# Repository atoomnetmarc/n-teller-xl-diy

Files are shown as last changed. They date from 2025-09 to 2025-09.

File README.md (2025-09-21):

**Status**: finished and working.

**Soldering and assembly time**: about 4 hours (if you can solder well).

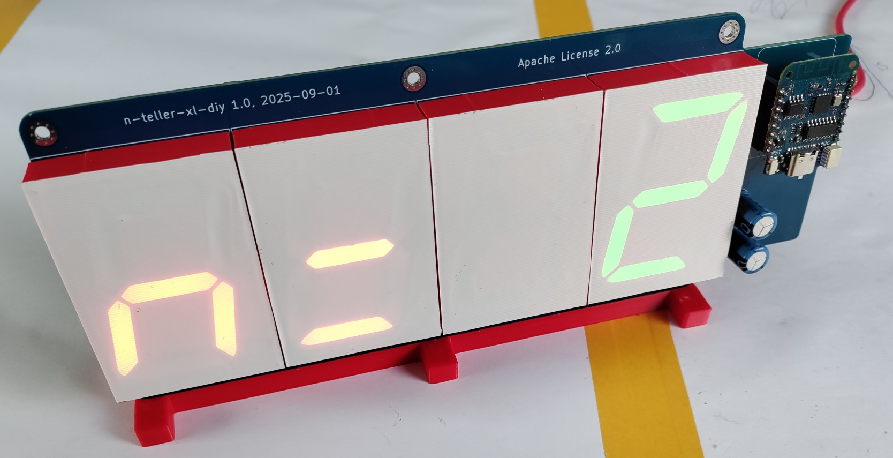
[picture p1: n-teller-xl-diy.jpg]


# n-teller-xl-diy

n-teller-xl-diy is an IoT device that displays the number of [checked in participants and visitors](https://revspace.nl/N) at the hackerspace called [Revelation Space (or RevSpace)](https://revspace.nl).

It connects to the [RevSpace MQTT server](https://revspace.nl/MQTT) via WiFi using an ESP8266.

The MQTT server publishes to [a few topics of interest](https://revspace.nl/MQTT#Topics) that are subscribed:

- revspace/[doorduino](https://revspace.nl/Doorduino3)/checked-in: this is the current total of checked-in people.
- revspace/[state](https://revspace.nl/Spacestatus): the current state (open or closed) of the hackerspace.

# Schematic

[hardware/n-teller-xl-diy-schematic.pdf](hardware/n-teller-xl-diy-schematic.pdf)

# BOM

See interactive BOM: [hardware/bom/](https://html-preview.github.io/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)

You will also need:

- The pcb. See [hardware/gerber/](hardware/gerber/) for gerber files. Order it at some PCB fabricator. You can also ask me for a bare PCB when I am at [RevSpace](https://revspace.nl/) hackerspace. I may have some left. I sell them for €5 a piece.
- 4x 3D prints of `7-segment 2.3 inch.stl` in opaque colored plastic. Use Gyroid infill for strong screw holes.
- 1x 3D print of `n-teller-xl-diy-stand.stl` in the color of your choice.
- 16x M2x10 self-tapping hex screws to mount the 4 7-segment 3D prints to the PCB.
- 3x M3x12 BHCS screws to mount the PCB to the 3D printed stand.
- About 28cm of 5cm wide vinyl white tape to stick onto the face of the 3D printed 7-segment digits. Or some other kind of 20x8cm thin white sticky plastic.

# Render

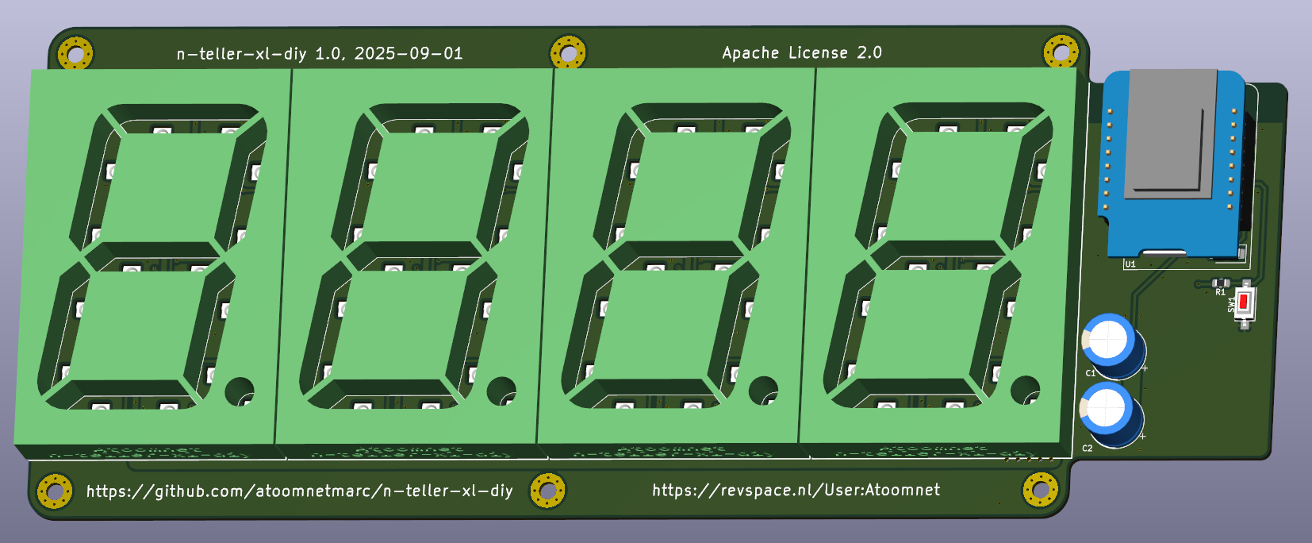
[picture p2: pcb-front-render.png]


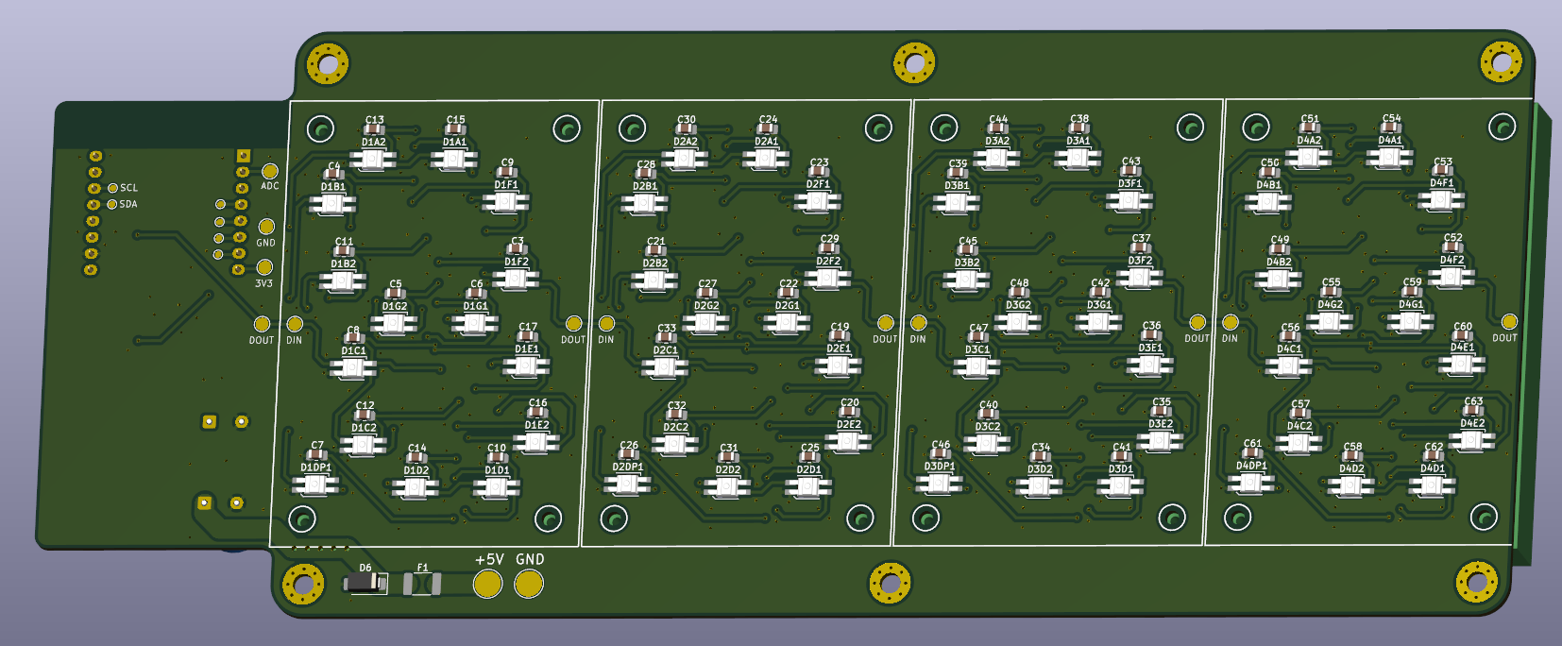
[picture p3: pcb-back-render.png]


# Assembly

Last time I made assembly instructions for the [n-teller](https://github.com/atoomnetmarc/n-teller) at https://revspace.nl/N-teller, but that was not used, everybody just asked what to do, even after telling there are assembly instructions.

So for this one I won't make instructions. Just follow the BOM and look at the pictures on this page, and figure things out yourself.

Use a 5V power supply that can provide at least 1A.

# Firmware

Compile and flash the firmware located in the [firmware directory](firmware/). You will need [PlatformIO](https://platformio.org/) for this. I recommend installing the [PlatformIO extension for VSCode](https://platformio.org/install/ide?install=vscode).

# Configure WiFi

Double press the reset button (somewhat slowly). The letters `AP` will appear on the display. Now connect to a WiFi network with a name like `nteller-bcddc2895fd2`. Then goto: http://192.168.4.1/ and configure your WiFi.

# (Frequently) Asked Questions

> Do I really need the level shifter?
>
> -- <cite>User that does not know that the high signal level of 3.3V is lower than the VIH (3.5V) of the SK6812</cite>

Oh, sure, because nothing says "reliable electronics" like ignoring basic signal integrity! No, you don't *really* need the level shifter. Just blob some solder on `JP1` and cross your fingers that your 3.3V signals magically play nice with those finicky SK6812s. But when your display starts glitching like it's possessed by a deranged hacker, don't you dare come whining to me – after all, you're the self-proclaimed expert who thought this was a brilliant idea. Good luck with that masterpiece!

On serious note. It depends. I had 2 batches of SK6812 LEDS's. One batch worked on 3.3V DIN, but VCC must be below 5.1V, any higher and it did not work. The other batch did not work, even after lowering VCC to below 4.5V. So, yes, you need a level shifter.



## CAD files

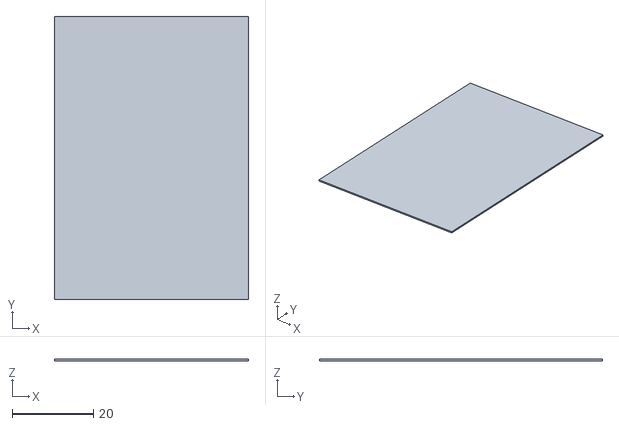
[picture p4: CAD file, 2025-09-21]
3d/7-segment 2.3 inch optional diffuser.stl
47.8 x 69.7 x 0.4

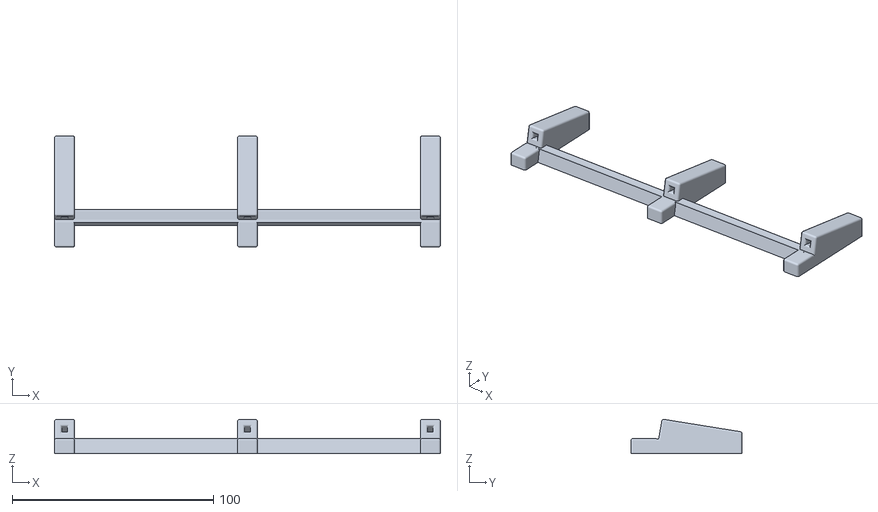
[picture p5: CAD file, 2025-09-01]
3d/n-teller-xl-diy-stand.stl
191.6 x 55.2 x 17.0

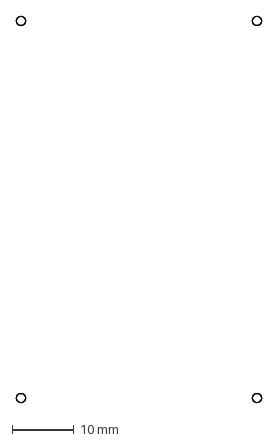
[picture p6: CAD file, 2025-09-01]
3d/7-segment 2.3 inch holes.dxf
39.6 x 62.5 mm

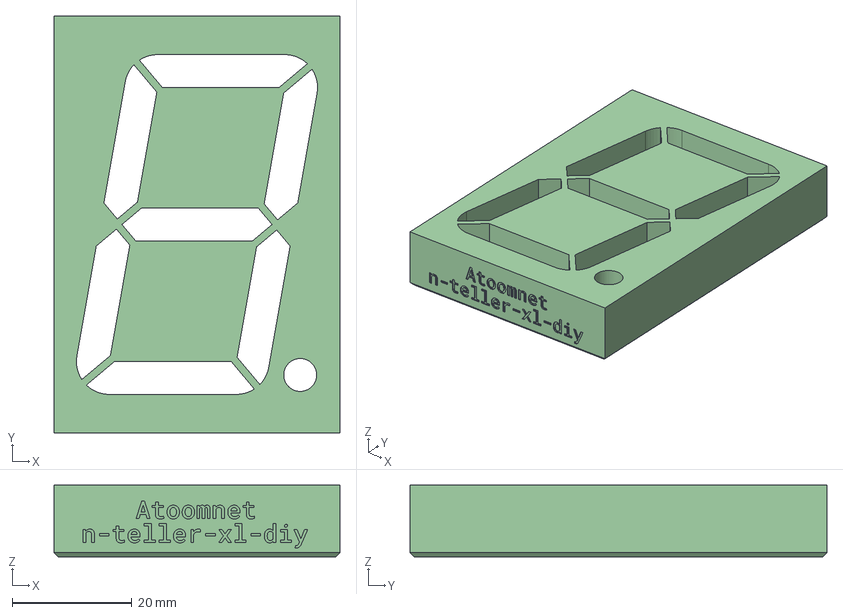
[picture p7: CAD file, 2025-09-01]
3d/7-segment 2.3 inch.step
47.8 x 69.7 x 12.0 mm

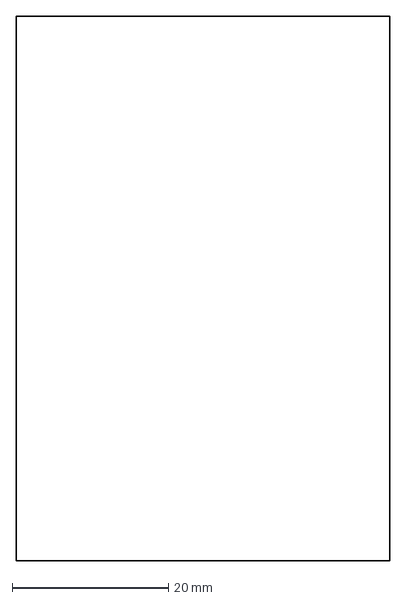
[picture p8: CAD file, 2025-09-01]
3d/7-segment 2.3 inch outline.dxf
47.8 x 69.7 mm

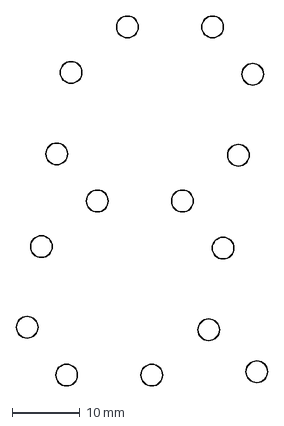
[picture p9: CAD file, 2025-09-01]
3d/7-segment 2.3 inch led position.dxf
37.1 x 54.5 mm

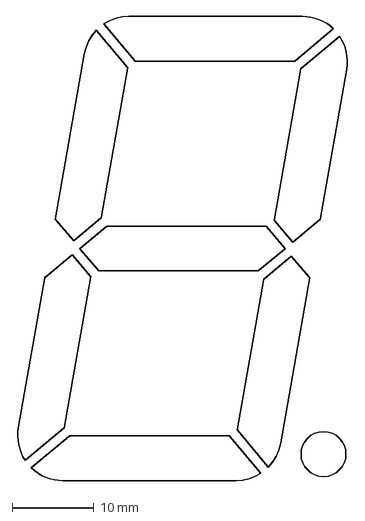
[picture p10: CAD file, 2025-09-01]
3d/7-segment 2.3 inch segments.dxf
40.6 x 56.8 mm

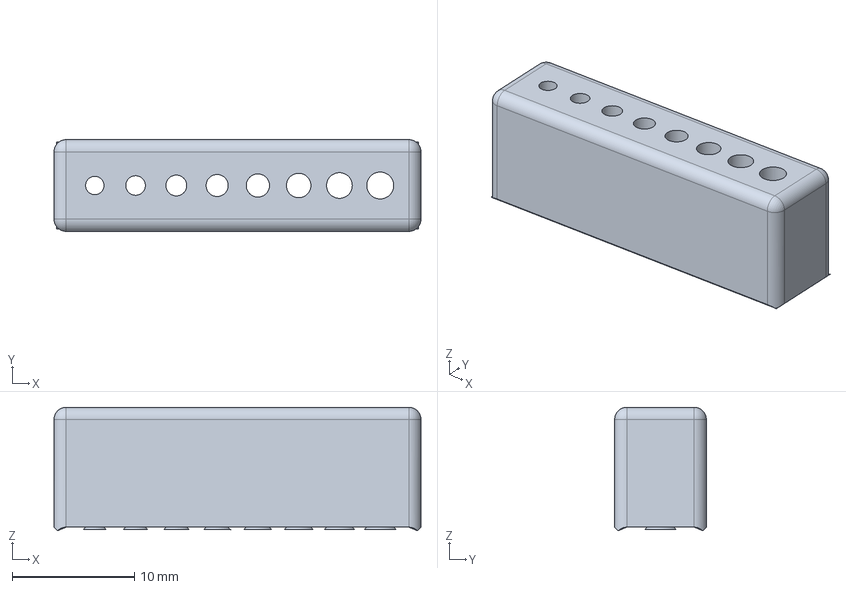
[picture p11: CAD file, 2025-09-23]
3d/m2x10 hole tester.FCStd
30.0 x 7.50 x 10.1 mm

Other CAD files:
3d/7-segment 2.3 inch.FCStd
3d/7-segment 2.3 inch.stl
3d/m2x10 hole tester.stl

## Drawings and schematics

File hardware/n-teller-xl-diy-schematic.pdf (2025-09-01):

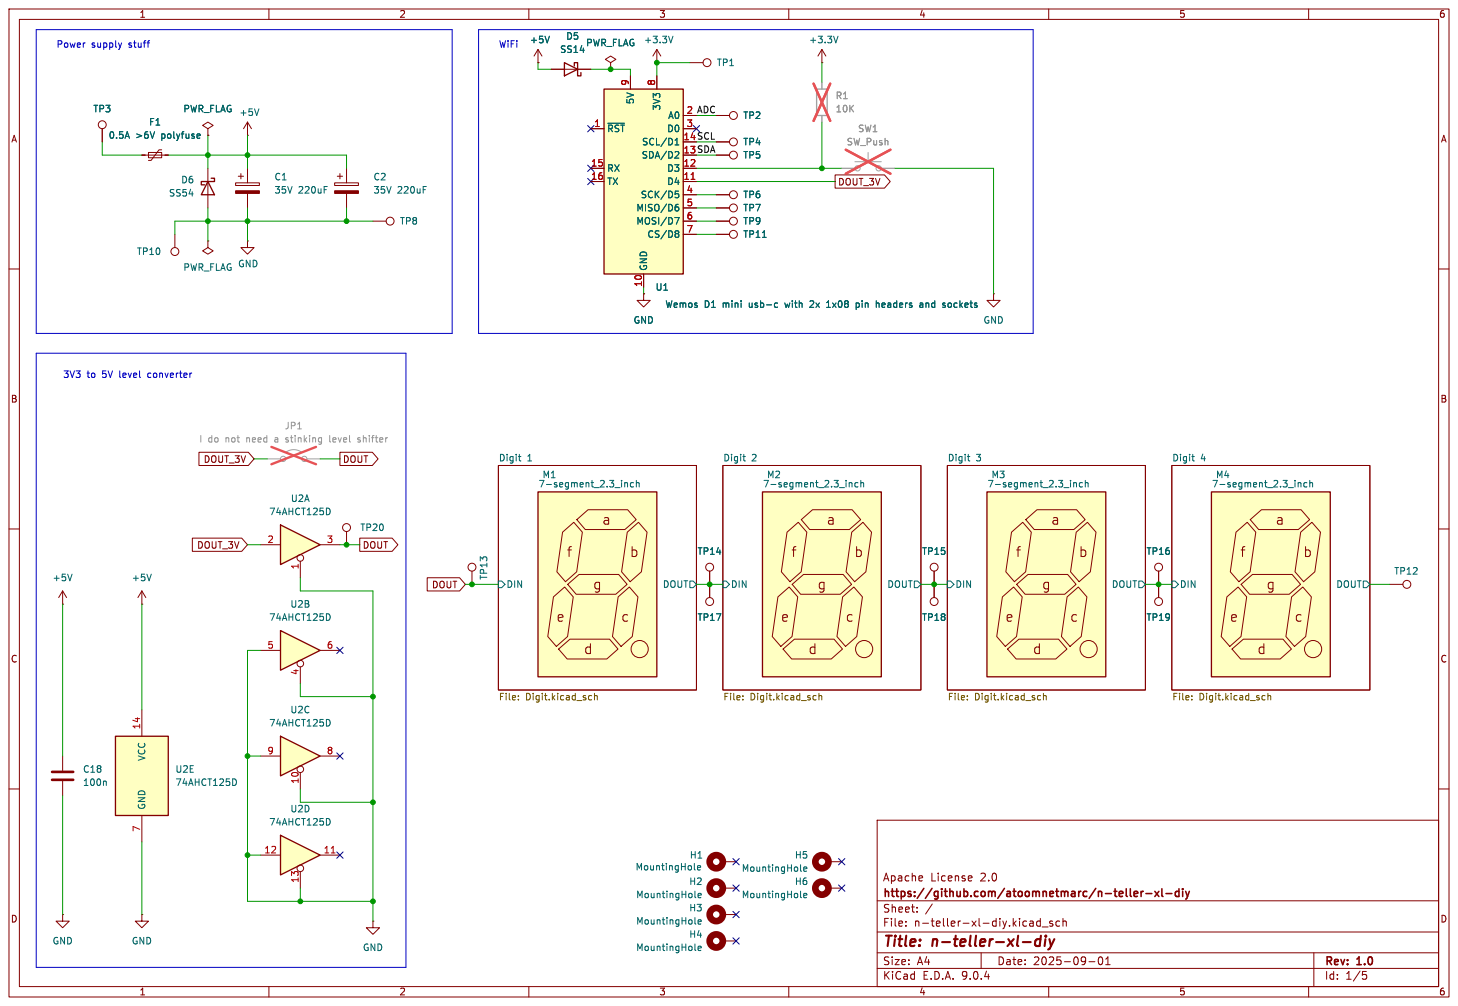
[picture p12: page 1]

8 A0 2 D0 3 SCL/D1 14 SDA/D2 13 D3 12 D4 11 SCK/D5 4 MISO/D6 5 MOSI/D7 6 CS/D8 7 SW1 SW_Push GND

8 A0 2 D0 3 SCL/D1 14 SDA/D2 13 D3 12 D4 11 SCK/D5 4 MISO/D6 5 MOSI/D7 6 CS/D8 7 U1Wemos D1 mini usb-c with 2x 1x08 pin headers and sockets TP5 TP6 TP7 H5 MountingHoleH6 MountingHole

File: n-teller-xl-diy.kicad_sch Sheet: / https://github.com/atoomnetmarc/n-teller-xl-diy

Id: 1/5 Title: n-teller-xl-diy

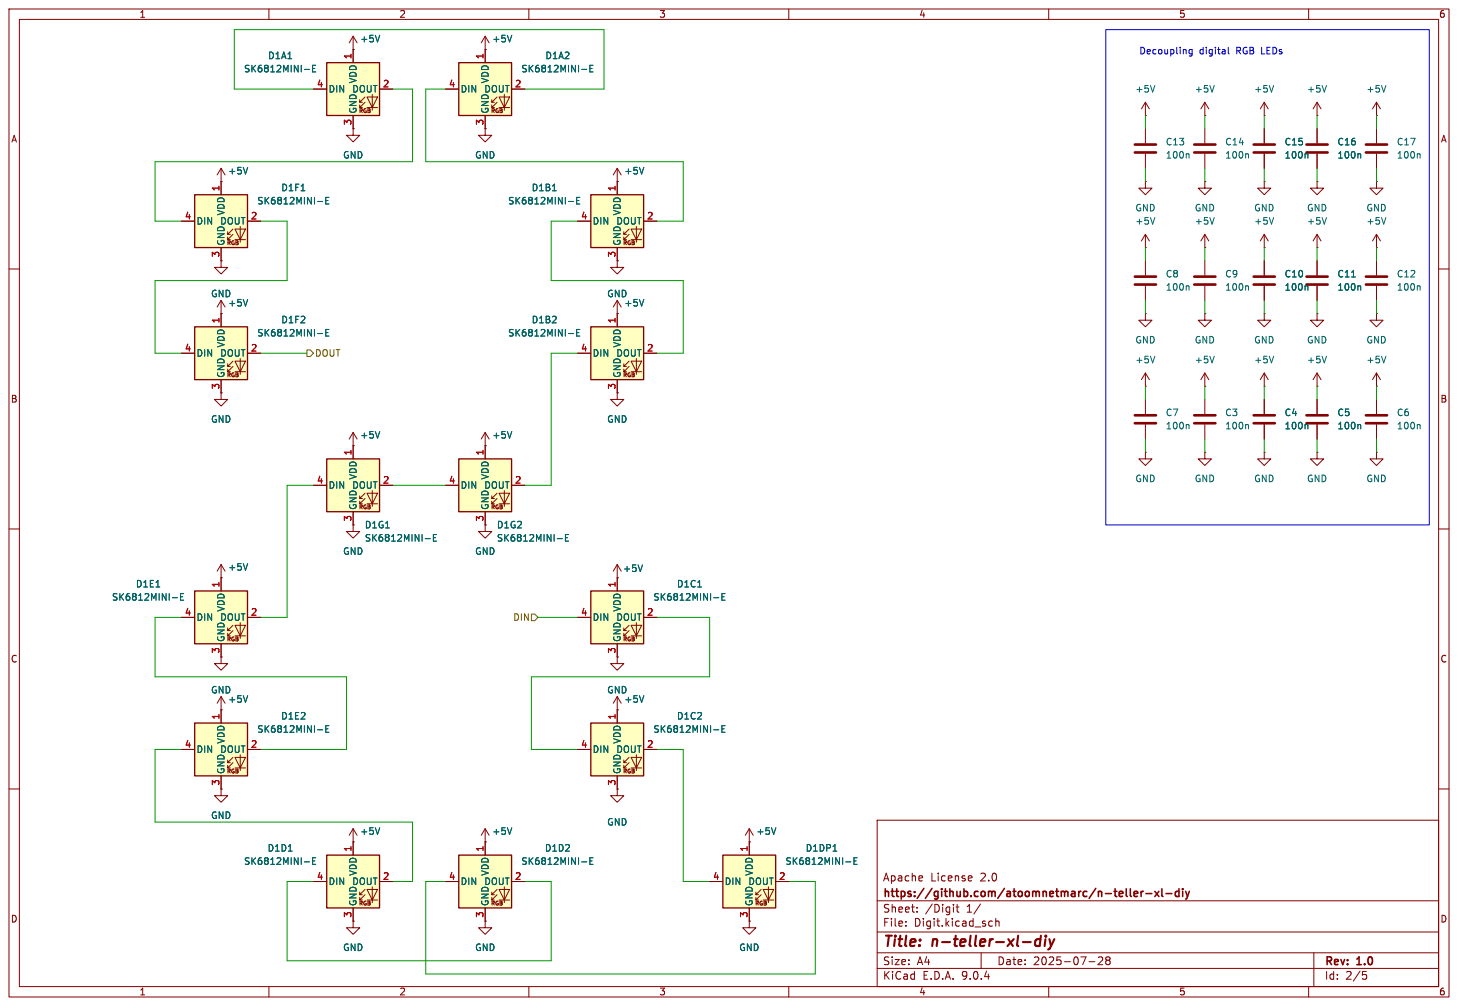
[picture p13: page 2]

Id: 2/5 Title: n-teller-xl-diy

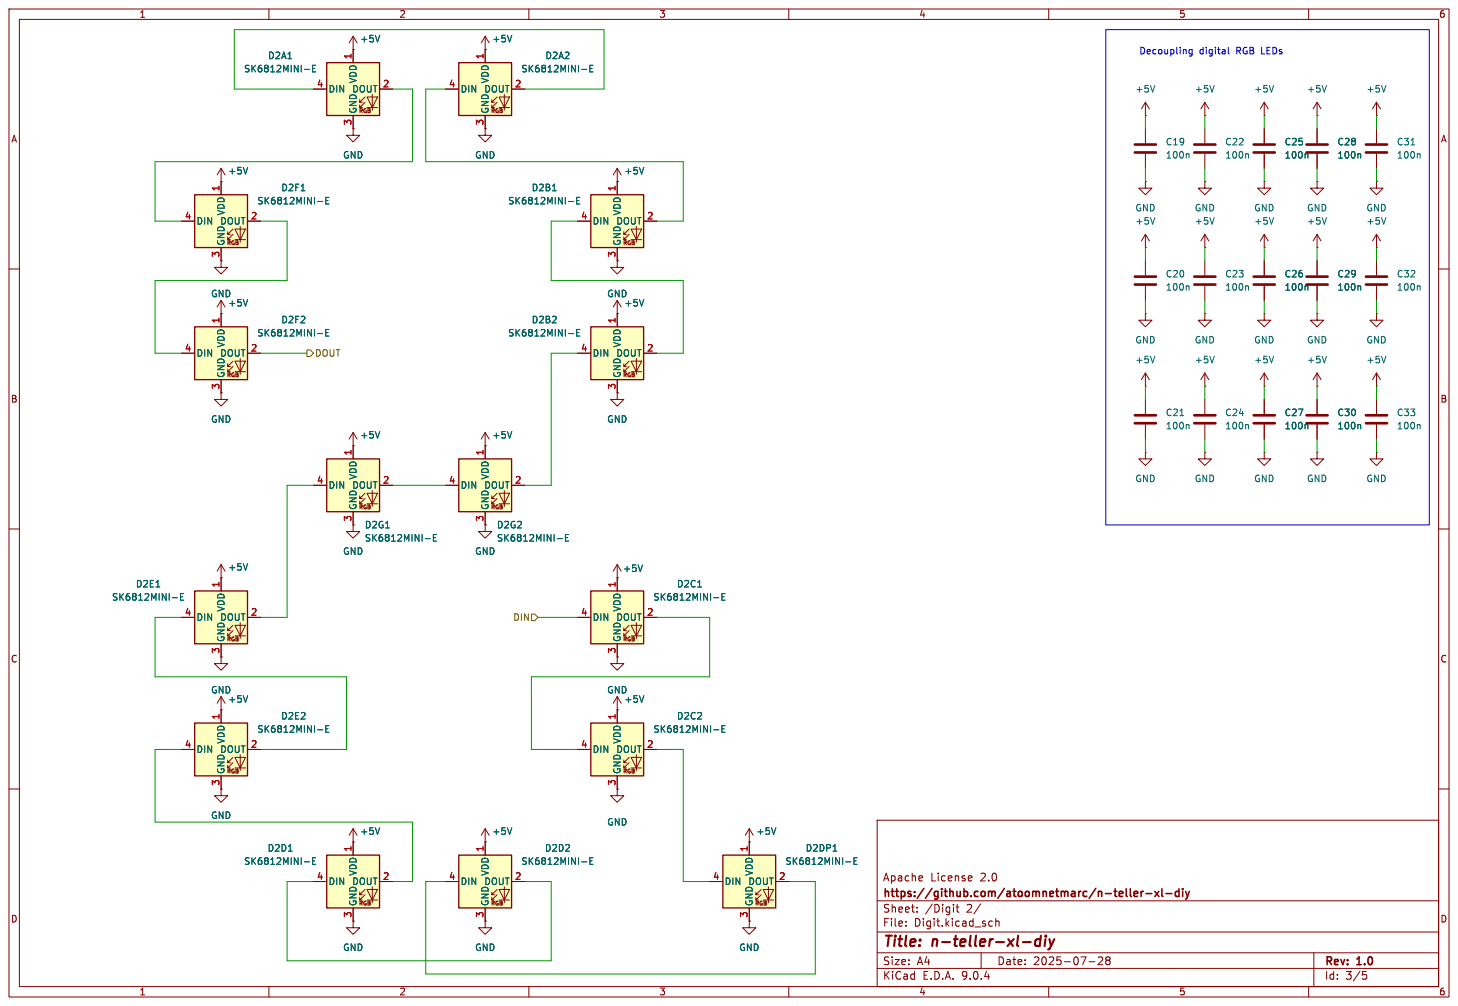
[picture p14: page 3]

Id: 3/5 Title: n-teller-xl-diy

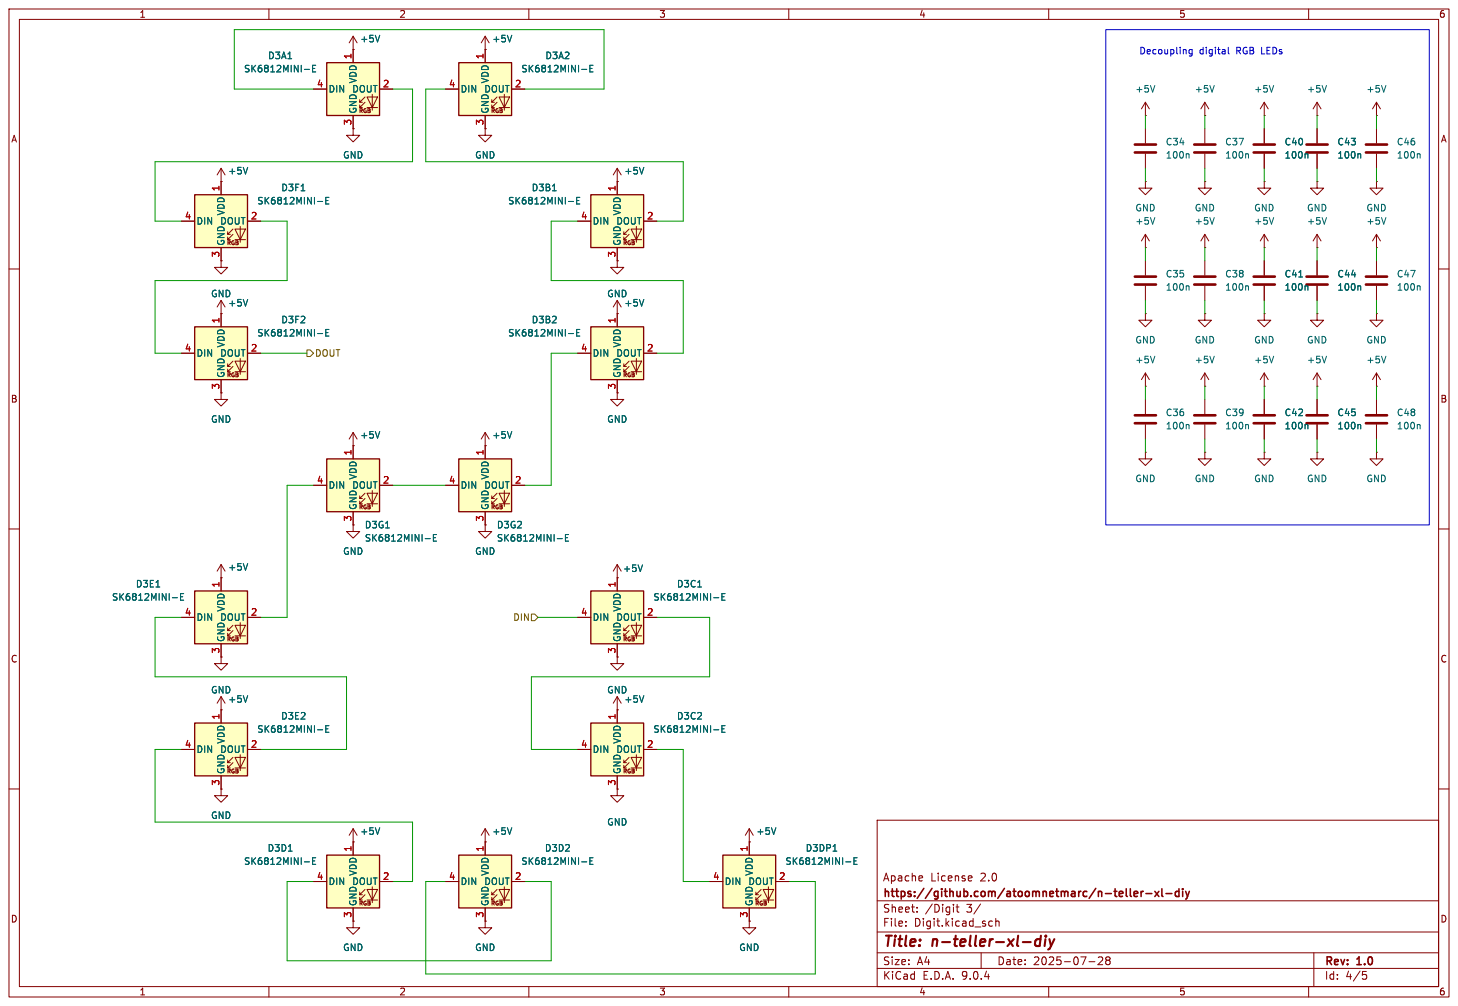
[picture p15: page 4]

Id: 4/5 Title: n-teller-xl-diy

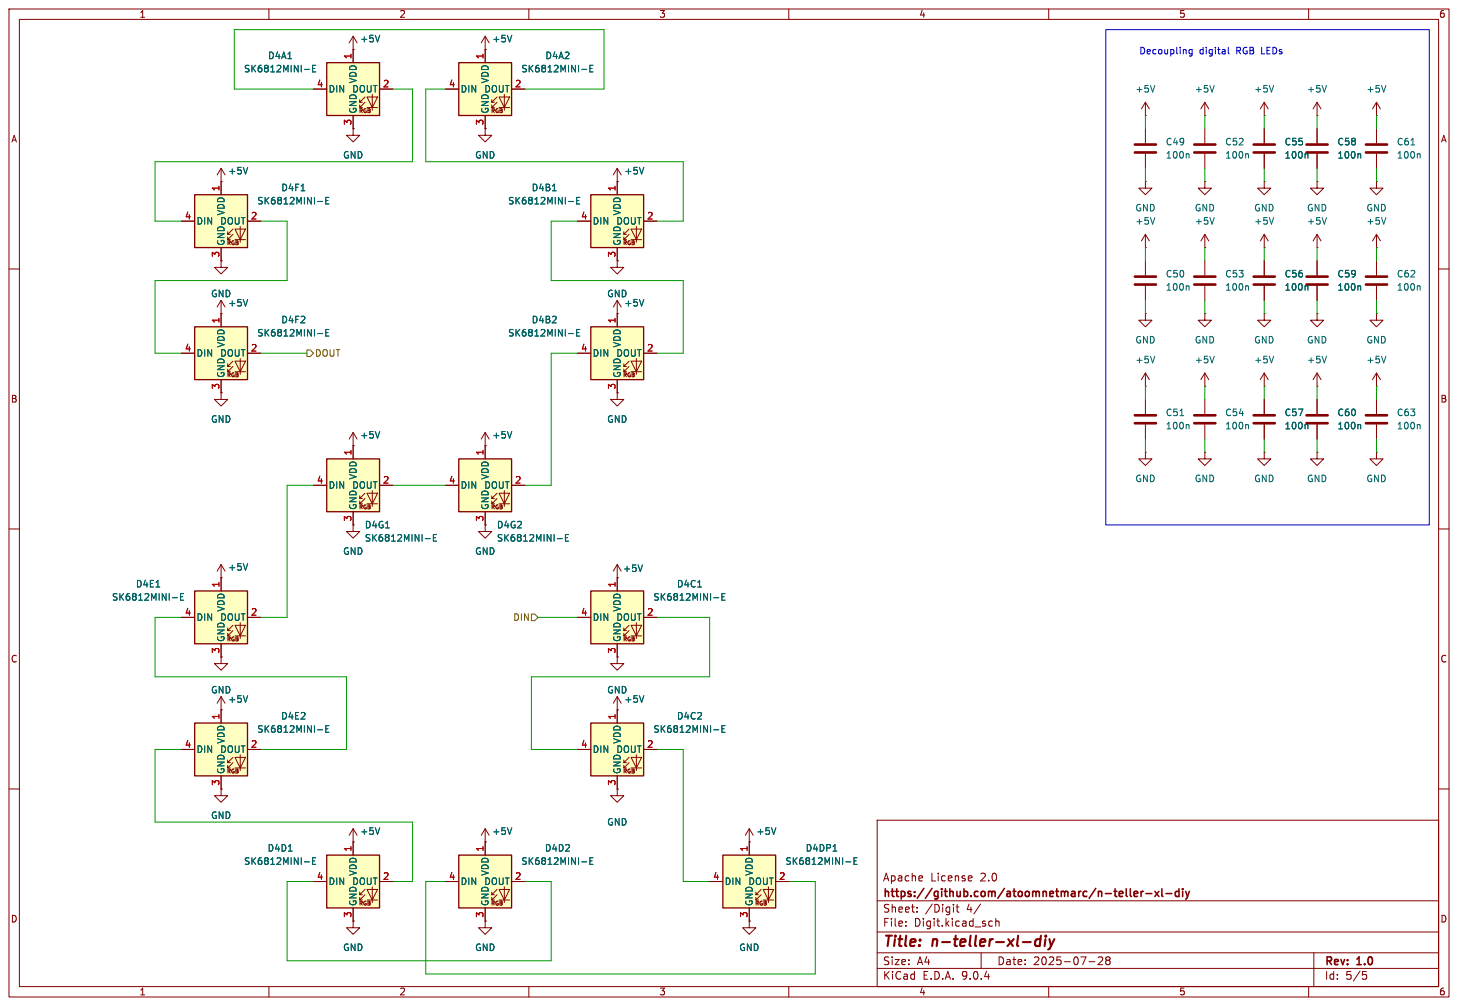
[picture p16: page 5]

Id: 5/5 Title: n-teller-xl-diy

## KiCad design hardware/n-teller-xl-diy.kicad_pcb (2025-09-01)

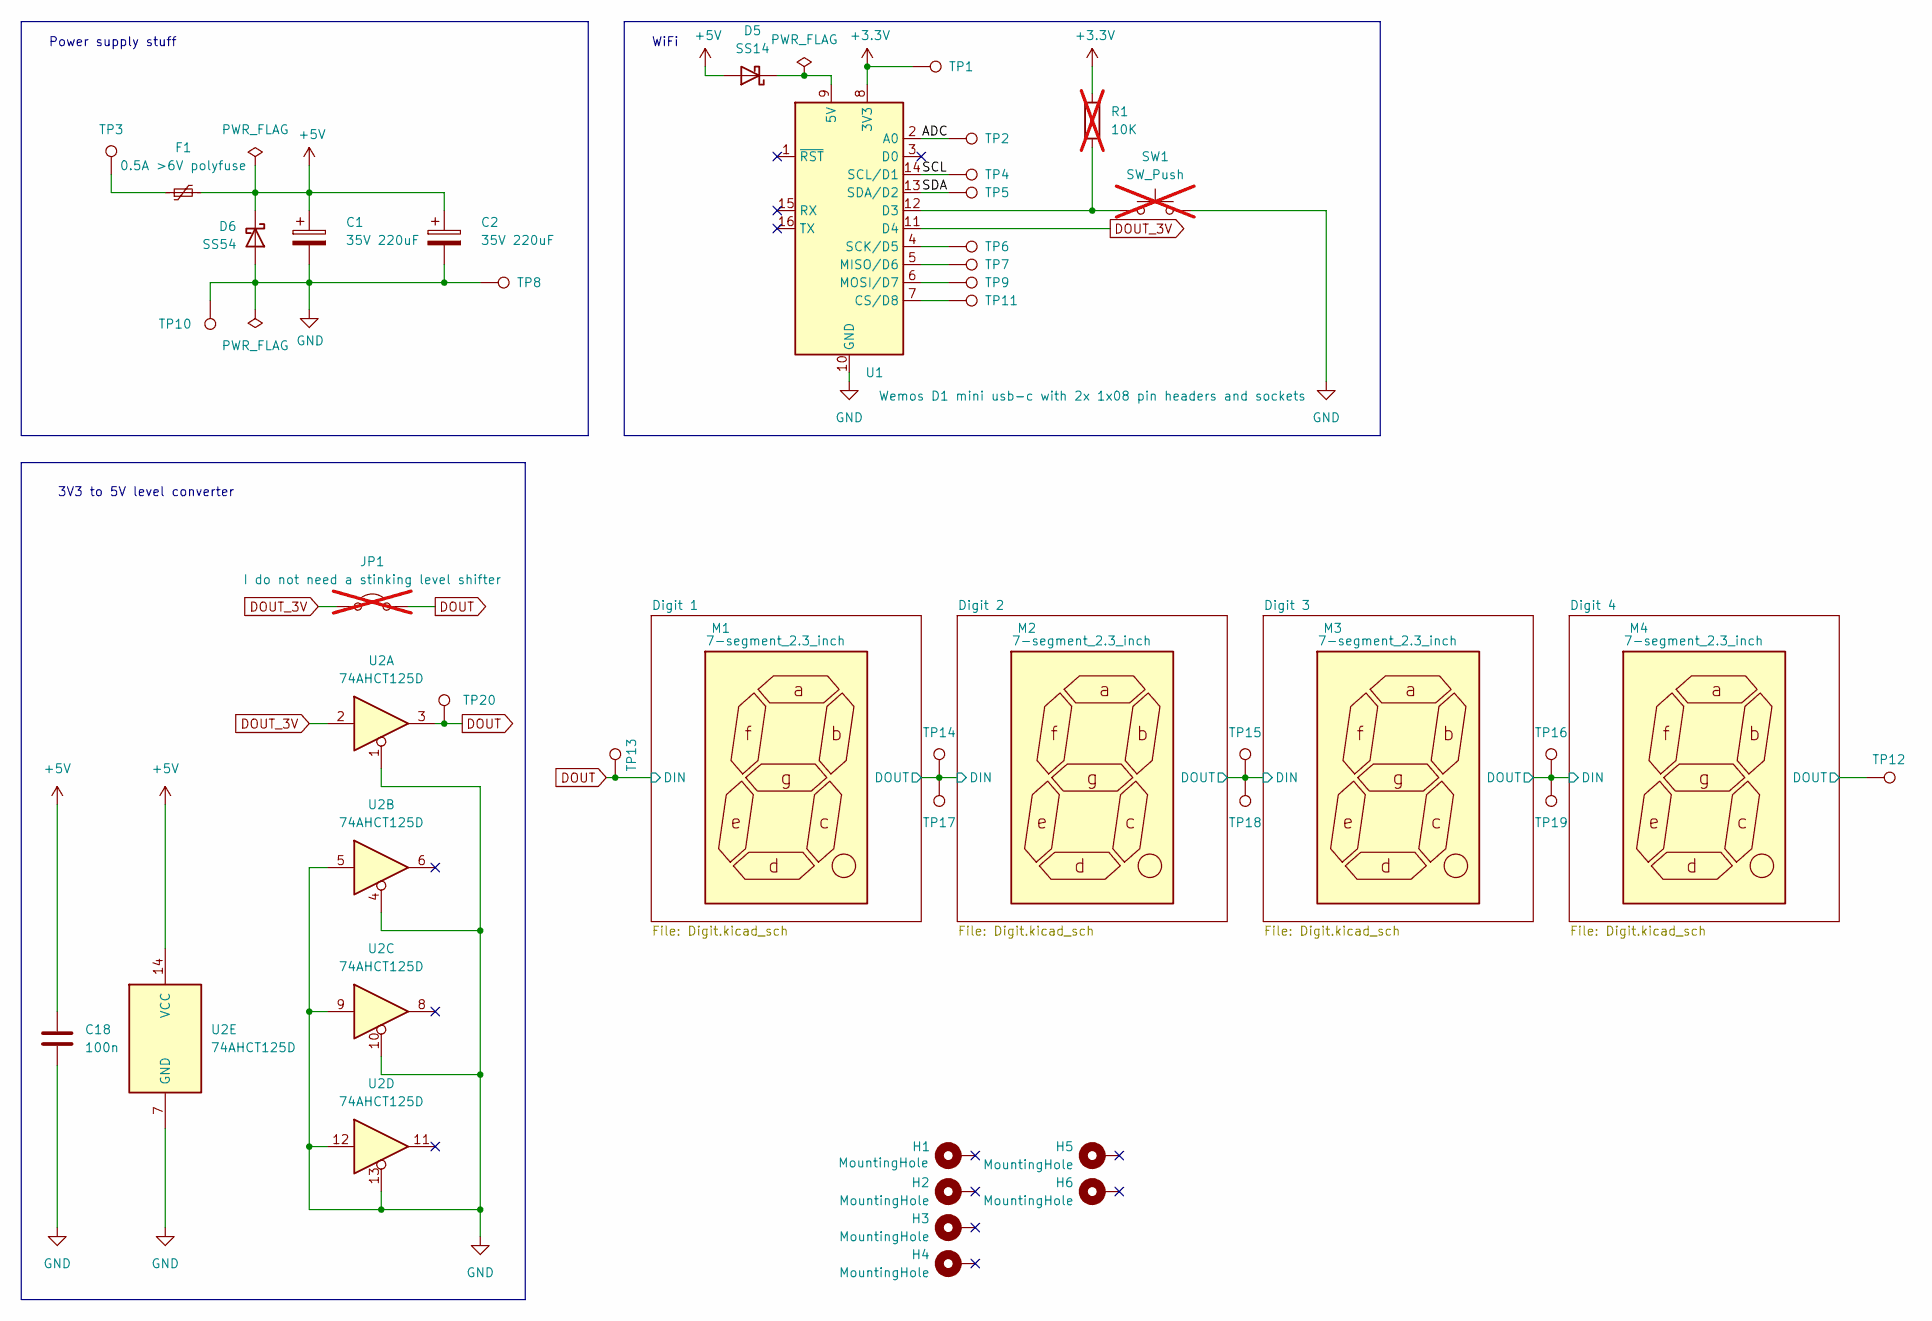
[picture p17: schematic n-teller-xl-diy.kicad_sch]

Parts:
C1, C2: 35V 220uF; CP_Radial_D10.0mm_P5.00mm
C18: 100n; C_0805_2012Metric_Pad1.18x1.45mm_HandSolder
D5: SS14; D_SMA
D6: SS54; D_SMA
F1: 0.5A >6V polyfuse; Fuse_1812_4532Metric_Pad1.30x3.40mm_HandSolder
H1, H2, H3, H4, H5, H6: MountingHole; MountingHole_3.2mm_M3_Pad_Via
JP1: I do not need a stinking level shifter; SolderJumper-2_P1.3mm_Open_TrianglePad1.0x1.5mm; not fitted
M1, M2, M3, M4: 7-segment_2.3_inch; 3d-printed 7-segment 2.3 inch
R1: 10K; R_0805_2012Metric_Pad1.20x1.40mm_HandSolder; not fitted
SW1: SW_Push; SW_SPST_CK_RS282G05A3; not fitted
TP1, TP2, TP8, TP12, TP13, TP14, TP15, TP16, TP17, TP18, TP19, TP20: TestPoint; TestPoint_Pad_D2.0mm
TP3, TP10: TestPoint; TestPoint_Pad_D4.0mm
TP4, TP5, TP6, TP7, TP9, TP11: TestPoint; TestPoint_Pad_D1.0mm
U1: Wemos D1 mini usb-c with 2x 1x08 pin headers and 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; WEMOS_D1_mini
U2: 74AHCT125D; SOIC-14_3.9x8.7mm_P1.27mm

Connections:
+3.3V: R1.2, TP1.1, U1.8 (3V3)
+5V: C1.1, C2.1, C18.1, D5.2 (A), D6.1 (K), F1.2, U2.14 (VCC); also elsewhere on the board
/ADC: TP2.1, U1.2 (A0)
/Digit 1/DOUT: TP14.1, TP17.1; also elsewhere on the board
/Digit 2/DOUT: TP15.1, TP18.1; also elsewhere on the board
/Digit 3/DOUT: TP16.1, TP19.1; also elsewhere on the board
/Digit 4/DOUT: TP12.1; also elsewhere on the board
/SCL: TP4.1, U1.14 (SCL/D1)
/SDA: TP5.1, U1.13 (SDA/D2)
DOUT: JP1.2 (B), TP13.1, TP20.1, U2.3; also elsewhere on the board
DOUT_3V: JP1.1 (A), U1.11 (D4), U2.2
GND: C1.2, C2.2, C18.2, D6.2 (A), SW1.1, TP8.1, TP10.1, U1.10 (GND), U2.1, U2.4, U2.5, U2.7 (GND), U2.9, U2.10, U2.12, U2.13; also elsewhere on the board
unnamed: D5.1 (K), U1.9 (5V)
unnamed: F1.1, TP3.1
unnamed: TP11.1, U1.7 (CS/D8)
unnamed: R1.1, SW1.2, U1.12 (D3)
unnamed: TP7.1, U1.5 (MISO/D6)
unnamed: TP9.1, U1.6 (MOSI/D7)
unnamed: TP6.1, U1.4 (SCK/D5)

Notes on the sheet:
WiFi
3V3 to 5V level converter
Power supply stuff

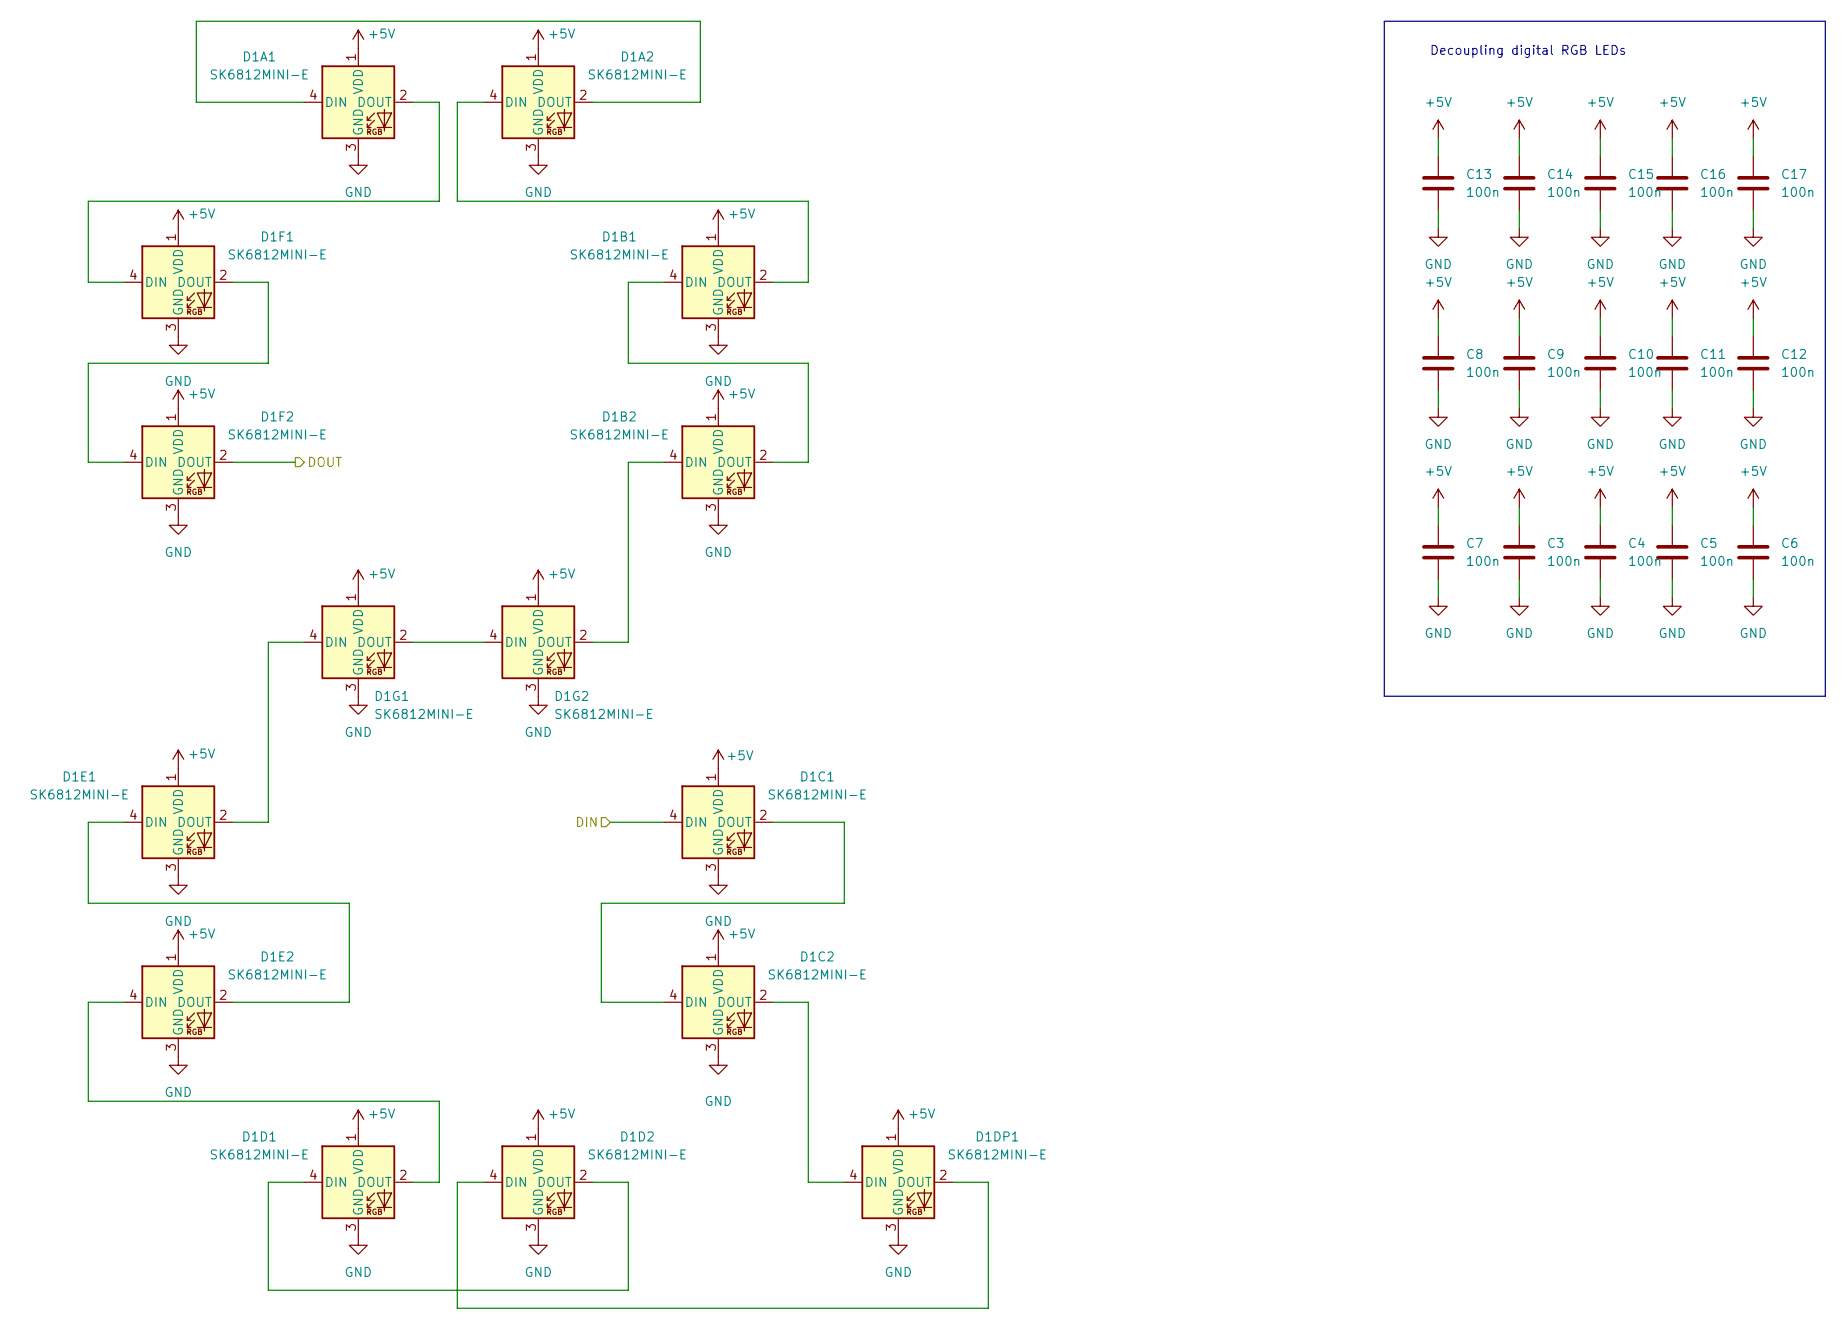
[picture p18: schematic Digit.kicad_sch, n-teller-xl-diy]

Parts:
C3, C4, C5, C6, C7, C8, C9, C10, C11, C12, C13, C14, C15, C16, C17: 100n; C_0805_2012Metric_Pad1.18x1.45mm_HandSolder
D1A1, D1A2, D1B1, D1B2, D1C1, D1C2, D1D1, D1D2, D1DP1, D1E1, D1E2, D1F1, D1F2, D1G1, D1G2: SK6812MINI-E; LED_SK6812MINI-E_3.2x2.8x1.78mm_P1.5mm

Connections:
+5V: C3.1, C4.1, C5.1, C6.1, C7.1, C8.1, C9.1, C10.1, C11.1, C12.1, C13.1, C14.1, C15.1, C16.1, C17.1, D1A1.1 (VDD), D1A2.1 (VDD), D1B1.1 (VDD), D1B2.1 (VDD), D1C1.1 (VDD), D1C2.1 (VDD), D1D1.1 (VDD), D1D2.1 (VDD), D1DP1.1 (VDD), D1E1.1 (VDD), D1E2.1 (VDD), D1F1.1 (VDD), D1F2.1 (VDD), D1G1.1 (VDD), D1G2.1 (VDD); also elsewhere on the board
/Digit 1/DOUT: D1F2.2 (DOUT); also elsewhere on the board
DOUT: D1C1.4 (DIN); also elsewhere on the board
GND: C3.2, C4.2, C5.2, C6.2, C7.2, C8.2, C9.2, C10.2, C11.2, C12.2, C13.2, C14.2, C15.2, C16.2, C17.2, D1A1.3 (GND), D1A2.3 (GND), D1B1.3 (GND), D1B2.3 (GND), D1C1.3 (GND), D1C2.3 (GND), D1D1.3 (GND), D1D2.3 (GND), D1DP1.3 (GND), D1E1.3 (GND), D1E2.3 (GND), D1F1.3 (GND), D1F2.3 (GND), D1G1.3 (GND), D1G2.3 (GND); also elsewhere on the board
unnamed: D1A1.4 (DIN), D1A2.2 (DOUT)
unnamed: D1A1.2 (DOUT), D1F1.4 (DIN)
unnamed: D1A2.4 (DIN), D1B1.2 (DOUT)
unnamed: D1B1.4 (DIN), D1B2.2 (DOUT)
unnamed: D1B2.4 (DIN), D1G2.2 (DOUT)
unnamed: D1C1.2 (DOUT), D1C2.4 (DIN)
unnamed: D1C2.2 (DOUT), D1DP1.4 (DIN)
unnamed: D1D1.4 (DIN), D1D2.2 (DOUT)
unnamed: D1D1.2 (DOUT), D1E2.4 (DIN)
unnamed: D1D2.4 (DIN), D1DP1.2 (DOUT)
unnamed: D1E1.4 (DIN), D1E2.2 (DOUT)
unnamed: D1E1.2 (DOUT), D1G1.4 (DIN)
unnamed: D1F1.2 (DOUT), D1F2.4 (DIN)
unnamed: D1G1.2 (DOUT), D1G2.4 (DIN)

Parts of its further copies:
C19, C20, C21, C22, C23, C24, C25, C26, C27, C28, C29, C30, C31, C32, C33, C34, C35, C36, C37, C38, C39, C40, C41, C42, C43, C44, C45, C46, C47, C48, C49, C50, C51, C52, C53, C54, C55, C56, C57, C58, C59, C60, C61, C62, C63: 100n; C_0805_2012Metric_Pad1.18x1.45mm_HandSolder
D2A1, D2A2, D2B1, D2B2, D2C1, D2C2, D2D1, D2D2, D2DP1, D2E1, D2E2, D2F1, D2F2, D2G1, D2G2, D3A1, D3A2, D3B1, D3B2, D3C1, D3C2, D3D1, D3D2, D3DP1, D3E1, D3E2, D3F1, D3F2, D3G1, D3G2, D4A1, D4A2, D4B1, D4B2, D4C1, D4C2, D4D1, D4D2, D4DP1, D4E1, D4E2, D4F1, D4F2, D4G1, D4G2: SK6812MINI-E; LED_SK6812MINI-E_3.2x2.8x1.78mm_P1.5mm

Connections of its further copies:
+5V: C19.1, C20.1, C21.1, C22.1, C23.1, C24.1, C25.1, C26.1, C27.1, C28.1, C29.1, C30.1, C31.1, C32.1, C33.1, C34.1, C35.1, C36.1, C37.1, C38.1, C39.1, C40.1, C41.1, C42.1, C43.1, C44.1, C45.1, C46.1, C47.1, C48.1, C49.1, C50.1, C51.1, C52.1, C53.1, C54.1, C55.1, C56.1, C57.1, C58.1, C59.1, C60.1, C61.1, C62.1, C63.1, D2A1.1 (VDD), D2A2.1 (VDD), D2B1.1 (VDD), D2B2.1 (VDD), D2C1.1 (VDD), D2C2.1 (VDD), D2D1.1 (VDD), D2D2.1 (VDD), D2DP1.1 (VDD), D2E1.1 (VDD), D2E2.1 (VDD), D2F1.1 (VDD), D2F2.1 (VDD), D2G1.1 (VDD), D2G2.1 (VDD), D3A1.1 (VDD), D3A2.1 (VDD), D3B1.1 (VDD), D3B2.1 (VDD), D3C1.1 (VDD), D3C2.1 (VDD), D3D1.1 (VDD), D3D2.1 (VDD), D3DP1.1 (VDD), D3E1.1 (VDD), D3E2.1 (VDD), D3F1.1 (VDD), D3F2.1 (VDD), D3G1.1 (VDD), D3G2.1 (VDD), D4A1.1 (VDD), D4A2.1 (VDD), D4B1.1 (VDD), D4B2.1 (VDD), D4C1.1 (VDD), D4C2.1 (VDD), D4D1.1 (VDD), D4D2.1 (VDD), D4DP1.1 (VDD), D4E1.1 (VDD), D4E2.1 (VDD), D4F1.1 (VDD), D4F2.1 (VDD), D4G1.1 (VDD), D4G2.1 (VDD); also elsewhere on the board
/Digit 1/DOUT: D2C1.4 (DIN); also elsewhere on the board
/Digit 2/DOUT: D2F2.2 (DOUT), D3C1.4 (DIN); also elsewhere on the board
/Digit 3/DOUT: D3F2.2 (DOUT), D4C1.4 (DIN); also elsewhere on the board
/Digit 4/DOUT: D4F2.2 (DOUT); also elsewhere on the board
GND: C19.2, C20.2, C21.2, C22.2, C23.2, C24.2, C25.2, C26.2, C27.2, C28.2, C29.2, C30.2, C31.2, C32.2, C33.2, C34.2, C35.2, C36.2, C37.2, C38.2, C39.2, C40.2, C41.2, C42.2, C43.2, C44.2, C45.2, C46.2, C47.2, C48.2, C49.2, C50.2, C51.2, C52.2, C53.2, C54.2, C55.2, C56.2, C57.2, C58.2, C59.2, C60.2, C61.2, C62.2, C63.2, D2A1.3 (GND), D2A2.3 (GND), D2B1.3 (GND), D2B2.3 (GND), D2C1.3 (GND), D2C2.3 (GND), D2D1.3 (GND), D2D2.3 (GND), D2DP1.3 (GND), D2E1.3 (GND), D2E2.3 (GND), D2F1.3 (GND), D2F2.3 (GND), D2G1.3 (GND), D2G2.3 (GND), D3A1.3 (GND), D3A2.3 (GND), D3B1.3 (GND), D3B2.3 (GND), D3C1.3 (GND), D3C2.3 (GND), D3D1.3 (GND), D3D2.3 (GND), D3DP1.3 (GND), D3E1.3 (GND), D3E2.3 (GND), D3F1.3 (GND), D3F2.3 (GND), D3G1.3 (GND), D3G2.3 (GND), D4A1.3 (GND), D4A2.3 (GND), D4B1.3 (GND), D4B2.3 (GND), D4C1.3 (GND), D4C2.3 (GND), D4D1.3 (GND), D4D2.3 (GND), D4DP1.3 (GND), D4E1.3 (GND), D4E2.3 (GND), D4F1.3 (GND), D4F2.3 (GND), D4G1.3 (GND), D4G2.3 (GND); also elsewhere on the board
unnamed: D2A1.4 (DIN), D2A2.2 (DOUT)
unnamed: D2A1.2 (DOUT), D2F1.4 (DIN)
unnamed: D2A2.4 (DIN), D2B1.2 (DOUT)
unnamed: D2B1.4 (DIN), D2B2.2 (DOUT)
unnamed: D2B2.4 (DIN), D2G2.2 (DOUT)
unnamed: D2C1.2 (DOUT), D2C2.4 (DIN)
unnamed: D2C2.2 (DOUT), D2DP1.4 (DIN)
unnamed: D2D1.4 (DIN), D2D2.2 (DOUT)
unnamed: D2D1.2 (DOUT), D2E2.4 (DIN)
unnamed: D2D2.4 (DIN), D2DP1.2 (DOUT)
unnamed: D2E1.4 (DIN), D2E2.2 (DOUT)
unnamed: D2E1.2 (DOUT), D2G1.4 (DIN)
unnamed: D2F1.2 (DOUT), D2F2.4 (DIN)
unnamed: D2G1.2 (DOUT), D2G2.4 (DIN)
unnamed: D3A1.4 (DIN), D3A2.2 (DOUT)
unnamed: D3A1.2 (DOUT), D3F1.4 (DIN)
unnamed: D3A2.4 (DIN), D3B1.2 (DOUT)
unnamed: D3B1.4 (DIN), D3B2.2 (DOUT)
unnamed: D3B2.4 (DIN), D3G2.2 (DOUT)
unnamed: D3C1.2 (DOUT), D3C2.4 (DIN)
unnamed: D3C2.2 (DOUT), D3DP1.4 (DIN)
unnamed: D3D1.4 (DIN), D3D2.2 (DOUT)
unnamed: D3D1.2 (DOUT), D3E2.4 (DIN)
unnamed: D3D2.4 (DIN), D3DP1.2 (DOUT)
unnamed: D3E1.4 (DIN), D3E2.2 (DOUT)
unnamed: D3E1.2 (DOUT), D3G1.4 (DIN)
unnamed: D3F1.2 (DOUT), D3F2.4 (DIN)
unnamed: D3G1.2 (DOUT), D3G2.4 (DIN)
unnamed: D4A1.4 (DIN), D4A2.2 (DOUT)
unnamed: D4A1.2 (DOUT), D4F1.4 (DIN)
unnamed: D4A2.4 (DIN), D4B1.2 (DOUT)
unnamed: D4B1.4 (DIN), D4B2.2 (DOUT)
unnamed: D4B2.4 (DIN), D4G2.2 (DOUT)
unnamed: D4C1.2 (DOUT), D4C2.4 (DIN)
unnamed: D4C2.2 (DOUT), D4DP1.4 (DIN)
unnamed: D4D1.4 (DIN), D4D2.2 (DOUT)
unnamed: D4D1.2 (DOUT), D4E2.4 (DIN)
unnamed: D4D2.4 (DIN), D4DP1.2 (DOUT)
unnamed: D4E1.4 (DIN), D4E2.2 (DOUT)
unnamed: D4E1.2 (DOUT), D4G1.4 (DIN)
unnamed: D4F1.2 (DOUT), D4F2.4 (DIN)
unnamed: D4G1.2 (DOUT), D4G2.4 (DIN)

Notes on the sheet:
Decoupling digital RGB LEDs

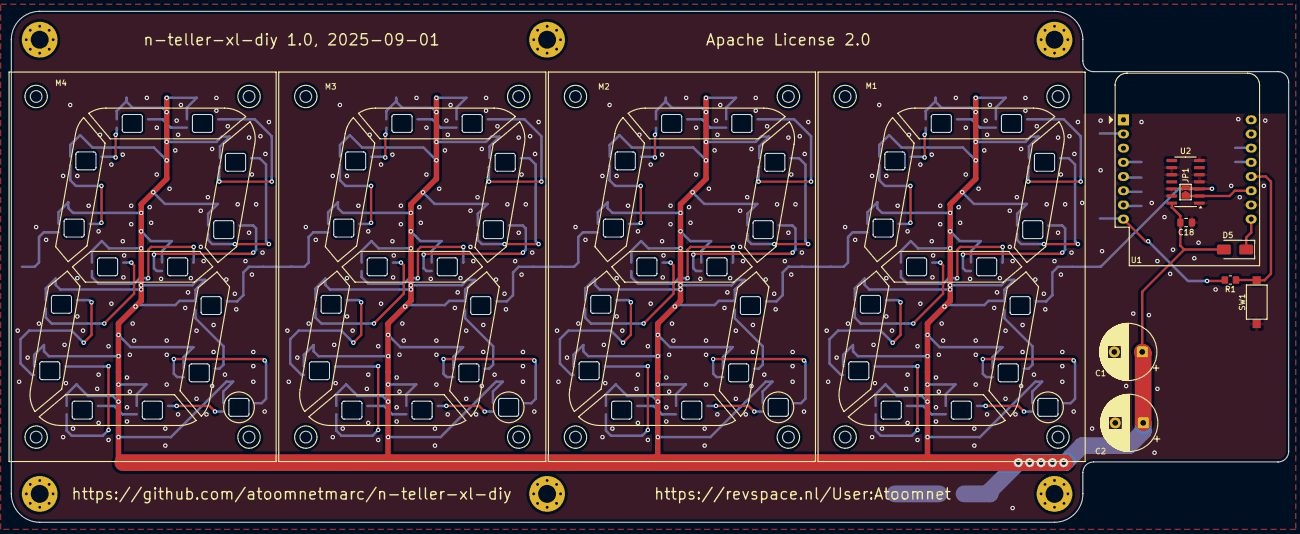
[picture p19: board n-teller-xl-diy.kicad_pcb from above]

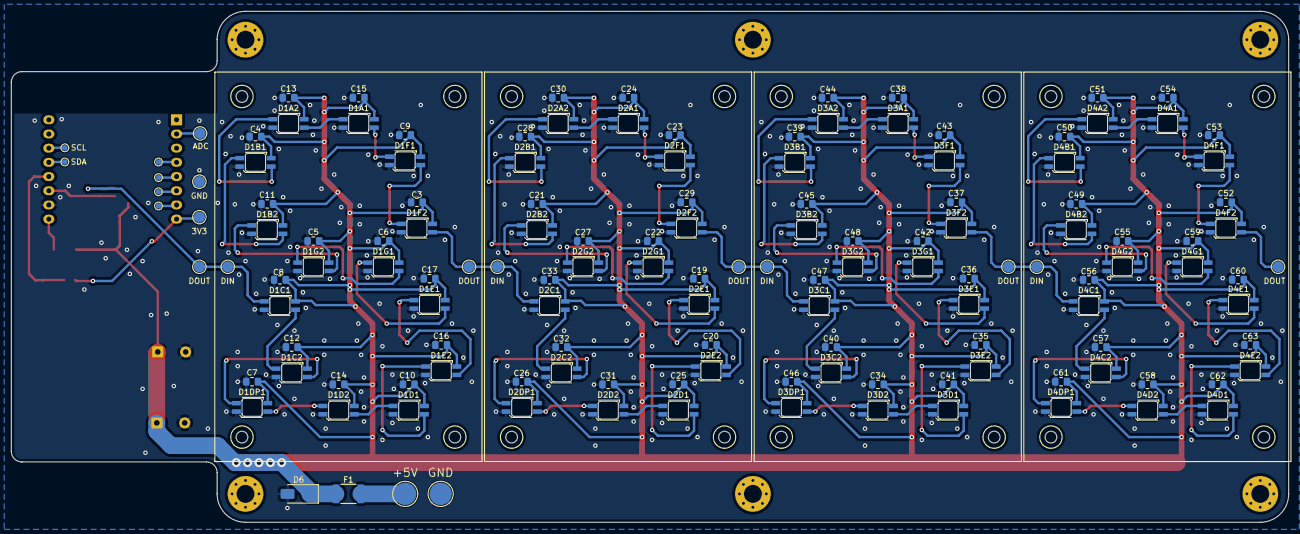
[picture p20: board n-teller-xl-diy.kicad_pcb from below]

Board: 2 copper layers, 228.6 x 91.4 mm, 161 parts (143 on the bottom side), 75 nets.

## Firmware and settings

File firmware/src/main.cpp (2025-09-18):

/*

Copyright 2025 Marc Ketel
SPDX-License-Identifier: Apache-2.0

*/

#include <Arduino.h>

#include <ESP8266WiFi.h>
#include <ESP8266mDNS.h>
#include <Ticker.h>

#include "Colors.h"
#include "DisplayManager.h"
#include <AsyncMqttClient.h>
#include <ESPAsyncWebServer.h>
#include <ESPAsyncWiFiManager.h>

#define ESP8266_DRD_USE_RTC       true
#define DOUBLERESETDETECTOR_DEBUG true
#define DRD_TIMEOUT               2
#define DRD_ADDRESS               0
#include <ESP_DoubleResetDetector.h>
DoubleResetDetector *drd;

DisplayManager display(4);

AsyncWebServer server(80);
DNSServer dns;

String name;

const char *mqtt_server = "revspace.nl";
AsyncMqttClient mqttClient;
Ticker mqttReconnectTimer;

WiFiEventHandler wifiConnectHandler;
WiFiEventHandler wifiDisconnectHandler;

/**
 * Connects to the MQTT server.
 * Initiates the MQTT client connection.
 */
void connectToMqtt() {
    Serial.println("Connecting to MQTT server");
    mqttClient.connect();
}

/**
 * Handles WiFi connection event.
 * Displays "viFi" on the LED strip and initiates MQTT connection.
 */
void onWifiConnect(const WiFiEventStationModeGotIP &event) {
    display.showText("viFi", COLOR_YELLOW);
    Serial.println("WiFi connected.");
    connectToMqtt();
}

/**
 * Handles WiFi disconnection event.
 * Logs the disconnection and detaches MQTT reconnect timer.
 */
void onWifiDisconnect(const WiFiEventStationModeDisconnected &event) {
    Serial.println("WiFi has disconnected.");
    mqttReconnectTimer.detach();
}

/**
 * Handles MQTT subscription acknowledgment.
 * Logs the successful subscription.
 */
void onMqttSubscribe(uint16_t packetId, uint8_t qos) {
    Serial.println("Subscription to topic acknowledged.");
}

/**
 * Handles MQTT connection event.
 * Displays "MQtt" on LED strip, logs connection, and subscribes to topics.
 */
void onMqttConnect(bool sessionPresent) {
    display.showText("MQtt", COLOR_YELLOW);
    Serial.println("Connected to MQTT server.");
    Serial.println("Subscribing topics.");
    mqttClient.subscribe("revspace/doorduino/checked-in", 0);
    mqttClient.subscribe("revspace/state", 0);
}

/**
 * Handles MQTT disconnection event.
 * Logs disconnection and schedules reconnect if WiFi is connected.
 */
void onMqttDisconnect(AsyncMqttClientDisconnectReason reason) {
    Serial.println("I seem to be disconnected from the MQTT server.");
    if (WiFi.isConnected()) {
        Serial.println("Lets reconnect to MQTT server.");
        mqttReconnectTimer.once(2, connectToMqtt);
    }
}

int16_t checkedin = 0;
uint8_t state = 0;

/**
 * Handles incoming MQTT messages.
 * Processes payloads for checked-in count and state topics, updates display accordingly.
 */
void onMqttMessage(char *topic, char *payload, AsyncMqttClientMessageProperties properties, size_t len, size_t index, size_t total) {
    String topicString = topic;

    Serial.print("A MQTT message has arrived on topic: ");
    Serial.println(topicString);

    // Do nothing if unexpected length is being published.
    if (len > 32) {
        Serial.println("Ignoring payload.");
        return;
    }

    Serial.print("MQTT payload: ");

    char payloadChars[len + 1];
    for (uint8_t i = 0; i < len; i++) {
        payloadChars[i] = payload[i];
    }
    payloadChars[len] = '\0';

    String payloadString = payloadChars;

    Serial.println(payloadString);

    if (topicString == "revspace/doorduino/checked-in") {
        checkedin = payloadString.toInt();
    }

    if (topicString == "revspace/state") {
        state = (payloadString == "open");
    }

    display.displayNumber(checkedin, state);
}

/**
 * Arduino setup function.
 * Initializes serial, display, WiFi, MQTT, mDNS, and web server; handles double reset for WiFi config.
 */
void setup() {
    drd = new DoubleResetDetector(DRD_TIMEOUT, DRD_ADDRESS);

    Serial.begin(115200);

    Serial.println("setup() starting.");

    String mac = WiFi.macAddress();
    mac.replace(":", "");
    mac.toLowerCase();
    name = "nteller-" + mac;

    Serial.print("Hello there! My hostname is ");
    Serial.println(name);

    Serial.println("Configuring LED strip.");
    display.initialize();

    Serial.println("Starting WiFi.");
    WiFi.hostname(name.c_str());
    WiFi.setSleepMode(WIFI_NONE_SLEEP);

    if (drd->detectDoubleReset()) {
        Serial.println("Double reset detected. Starting wifimanager.");
        display.showText("_AP_", COLOR_YELLOW);

        AsyncWiFiManager wifiManager(&server, &dns);
        wifiManager.setTimeout(300);
        if (!wifiManager.startConfigPortal(name.c_str())) {
            Serial.println("Failed to connect and hit timeout.");
            ESP.restart();
        }

        Serial.println("Our new WiFi credentials seem to work!");
    } else {

        // All LEDS are currently blue
        delay(2500);

        // All LEDS green
        display.all(COLOR_GREEN);
        display.strip.Show();
        delay(2500);

        // All LEDS red
        display.all(COLOR_RED);
        display.strip.Show();
        delay(2500);

        // All LEDS yellow
        display.all(COLOR_YELLOW);
        display.strip.Show();

        display.showText("Conn", COLOR_YELLOW);

        WiFi.begin();
    }



    wifiConnectHandler = WiFi.onStationModeGotIP(onWifiConnect);
    wifiDisconnectHandler = WiFi.onStationModeDisconnected(onWifiDisconnect);

    mqttClient.onConnect(onMqttConnect);
    mqttClient.onDisconnect(onMqttDisconnect);
    mqttClient.onSubscribe(onMqttSubscribe);
    mqttClient.onMessage(onMqttMessage);
    mqttClient.setClientId(name.c_str());
    mqttClient.setServer(mqtt_server, 1883);

    if (!MDNS.begin(name.c_str())) {
        Serial.println("Error starting mDNS.");
    } else {
        Serial.println("mDNS started.");
    }

    Serial.println("Configuring async webserver.");
    server.on("/", HTTP_GET, [](AsyncWebServerRequest *request) {
        request->send(200, "text/plain", name);
    });

    Serial.println("setup() done.");
}

/**
 * Arduino loop function.
 * Updates mDNS and double reset detector periodically.
 */
void loop() {
    MDNS.update();
    drd->loop();
}

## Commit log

2025-09-18 Add startup LED debug patterns.
2025-09-21 3d-print hint.
2025-09-21 Add optional 3d-printable diffuser.
    [7-segment 2.3 inch optional diffuser.stl, 7-segment 2.3 inch.FCStd]
2025-09-23 Enlarge m2x10 holes from 1.5mm to 1.9mm.
    [7-segment 2.3 inch.FCStd, 7-segment 2.3 inch.stl, m2x10 hole tester.FCStd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]

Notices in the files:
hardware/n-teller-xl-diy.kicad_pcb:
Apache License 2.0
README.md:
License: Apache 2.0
